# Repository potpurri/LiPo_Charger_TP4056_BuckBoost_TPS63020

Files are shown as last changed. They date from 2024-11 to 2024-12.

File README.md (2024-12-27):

# Lithium Battery Charger and Boost Converter PCB

This PCB is designed to safely charge a lithium-ion cell and provide a selectable 3.3V or 5V output. It's equipped with components that ensure safe charging and protection for the battery and supports flexible output and charging options. 

## Features

- **Charging IC**: TP4056 with adjustable charge currents.
- **Protection Circuitry**: DW01A and F8205A provide overcharge, over-discharge, and overcurrent protection.
- **Buck-Boost Converter**: TPS63020 for stable 3.3V or 5V output, selectable via solder jumper.
- **Compact Design**: Ideal for portable applications, with both top and bottom images of the board for easy identification.
- **Fuse Protection**: Added fuse for enhanced safety of the battery connection.
- **Battery disconnection during charging**: When the USB-C port is connected for charging, the battery is disconnected from the Buck-Boost converter via two p-channel MOSFETs in series, with the gates tied to VBUS of the USB-C input. Power is instead provided to the Buck-Boost converter using a Schottky diode during charging. This circuit can be bypassed using the solder jumper on the bottom side of the PCB.

## Charging Current Settings

The charging current of the TP4056 can be adjusted using solder jumpers on the PCB to meet various requirements. Refer to the table below:

| Solder Jumper Setting | Charging Current |
|---|---|
| J1 | 130 mA |
| J2 | 280 mA |
| J3 | 400 mA |
| J4 | 580 mA |
| J5 | 780 mA |
| J6 | 1000 mA |

## Images

### Schematic
Schematic

### 3D Renderings
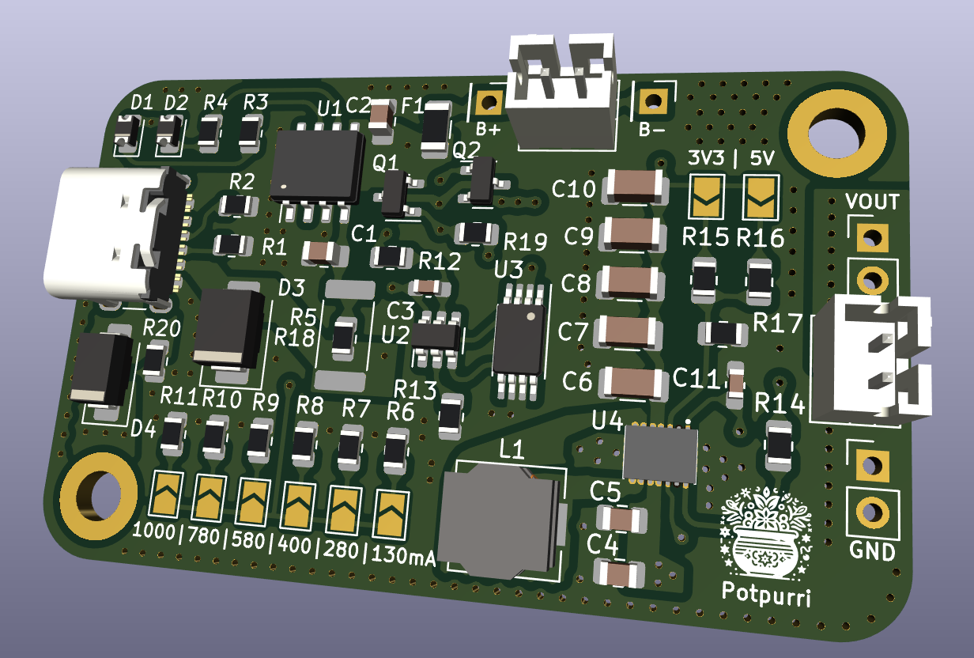
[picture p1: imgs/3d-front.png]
3D Front
- Front View: 
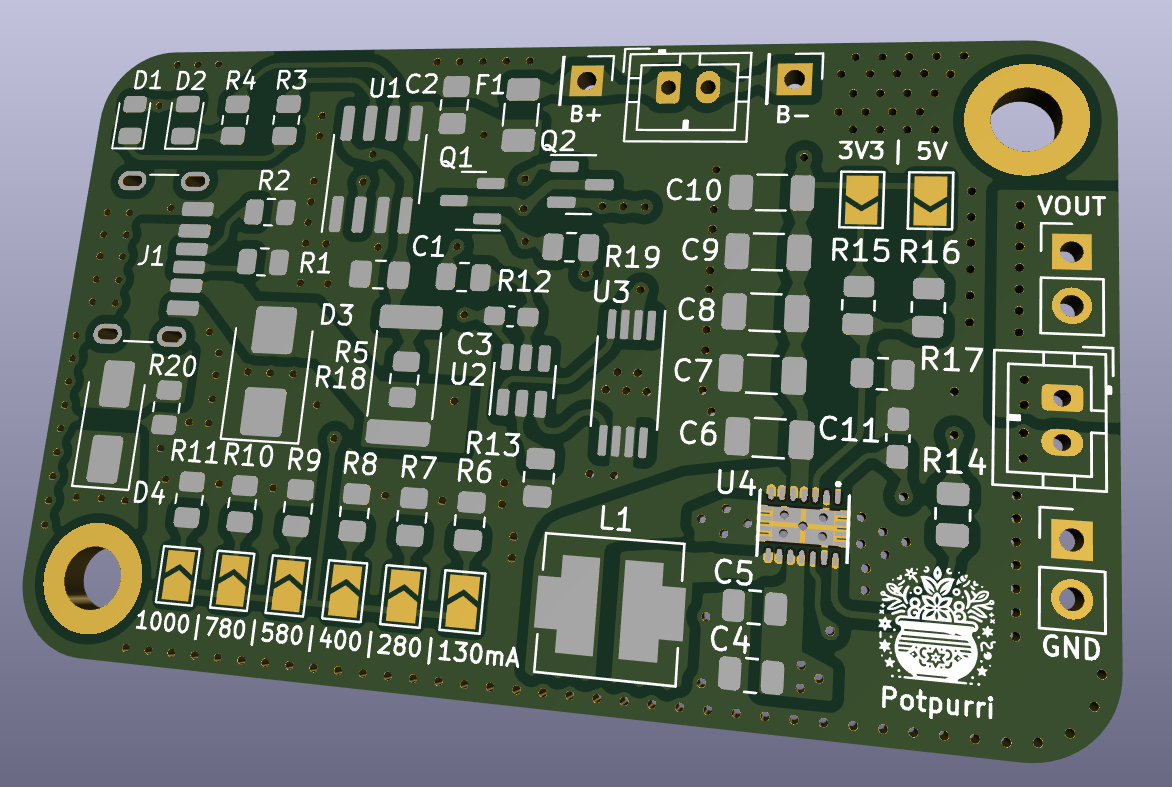
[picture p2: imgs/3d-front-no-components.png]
3D Front
- Front View Without Components: 
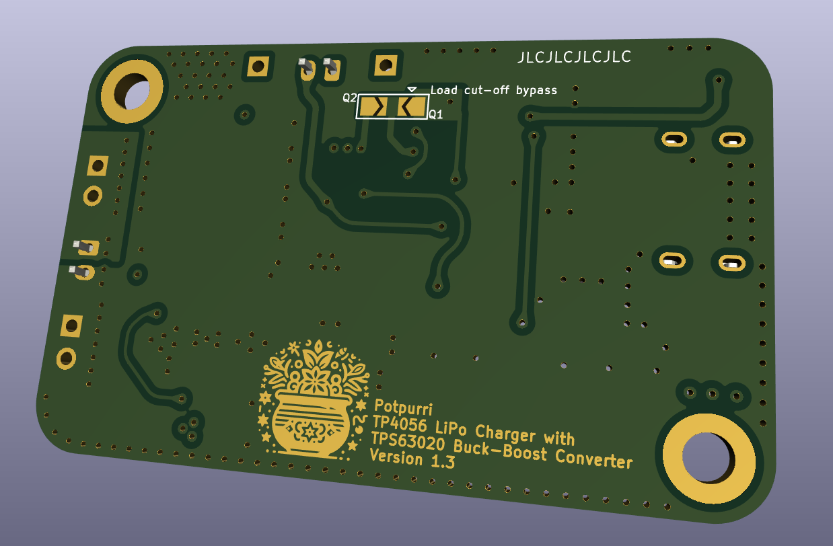
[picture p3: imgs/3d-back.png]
3D Back
- Back View: 

### PCB
**4-Layer Stackup**: Signal Layer, GND Layer, Power Layer, Signal Layer
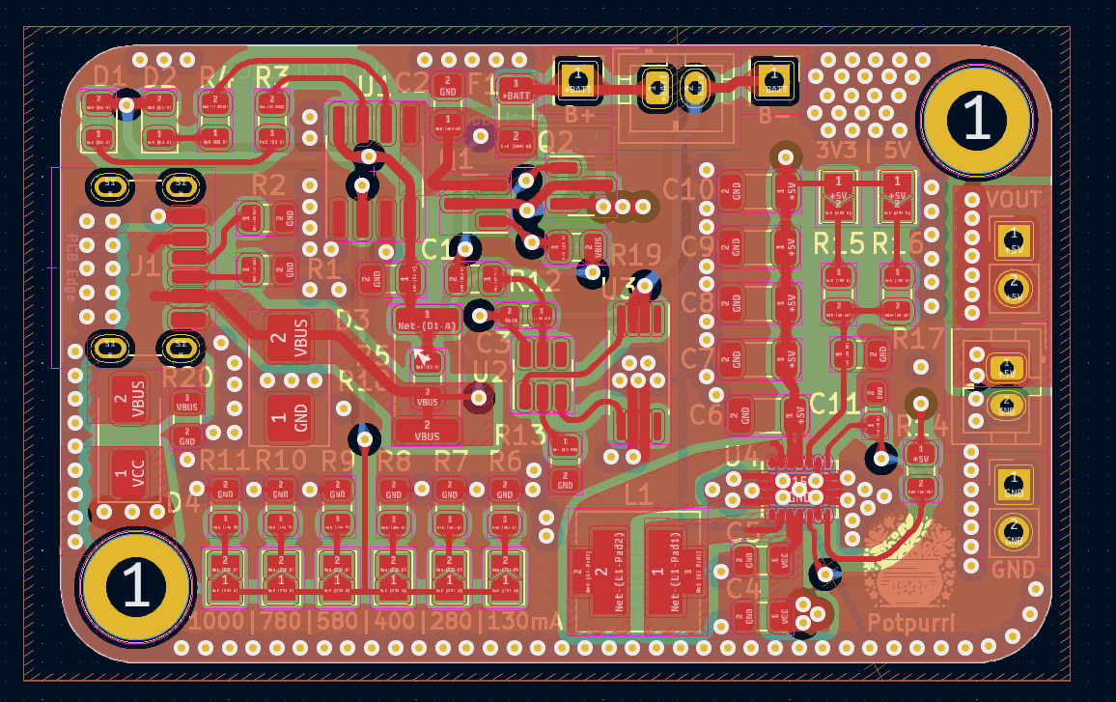
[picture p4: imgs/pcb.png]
PCB - All Layers
- All layers: 
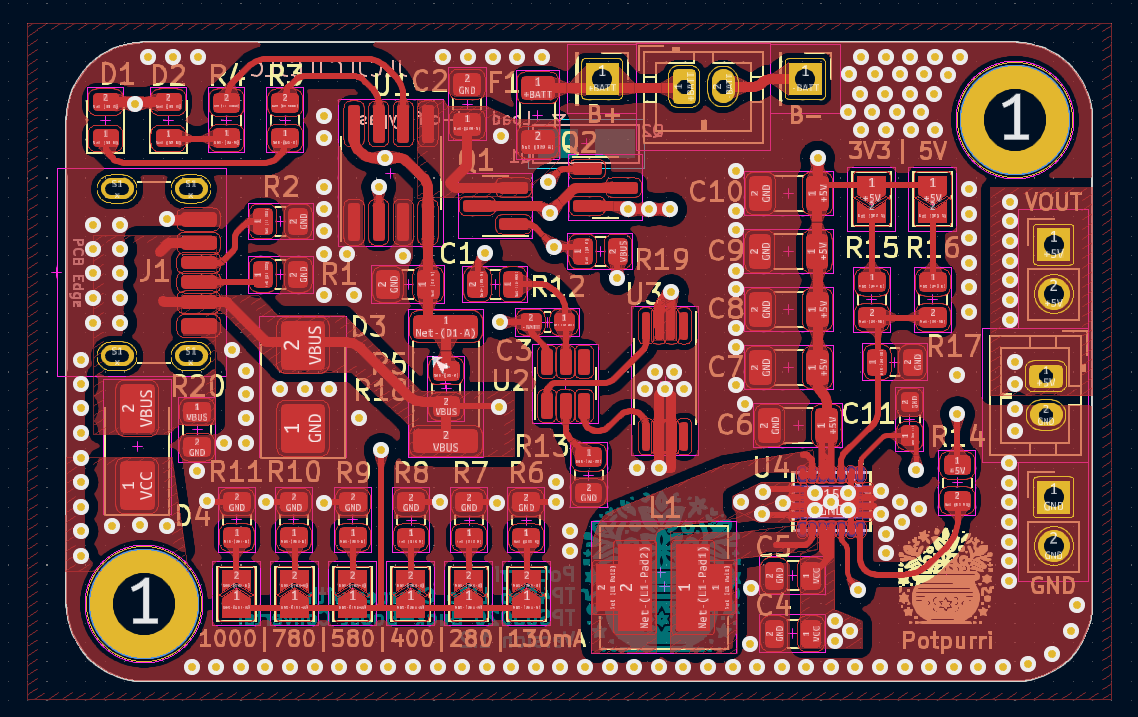
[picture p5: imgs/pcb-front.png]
PCB - Front
- Front traces: 
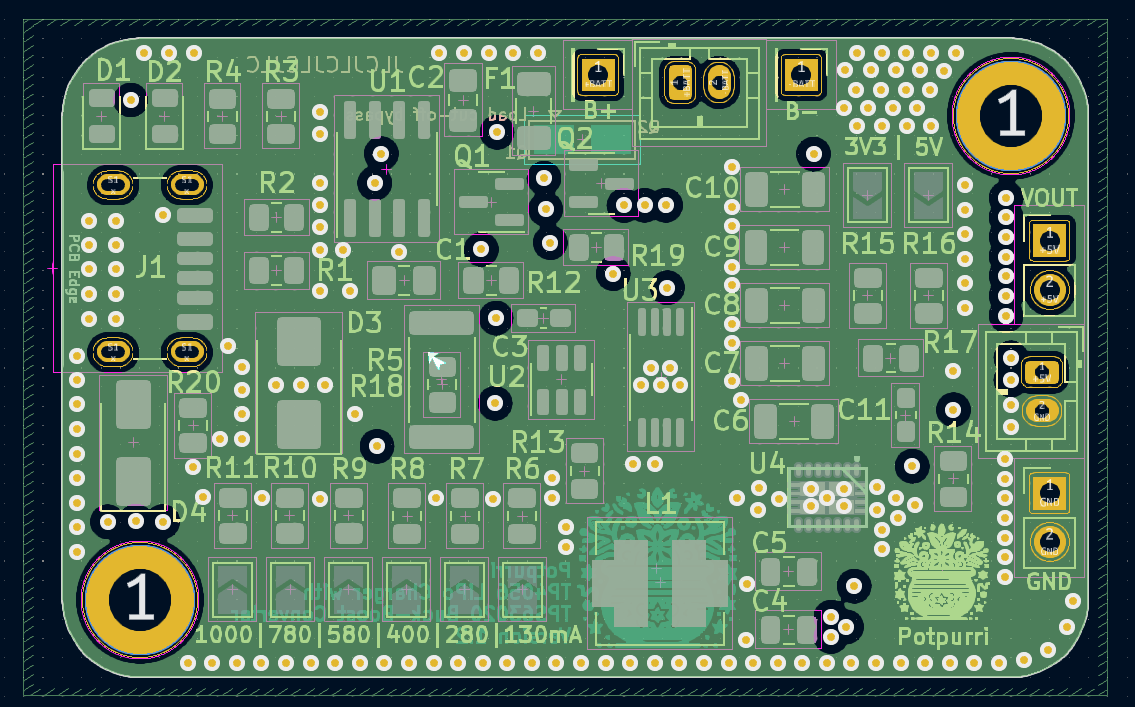
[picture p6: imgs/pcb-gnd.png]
PCB - GND
- GND plane: 
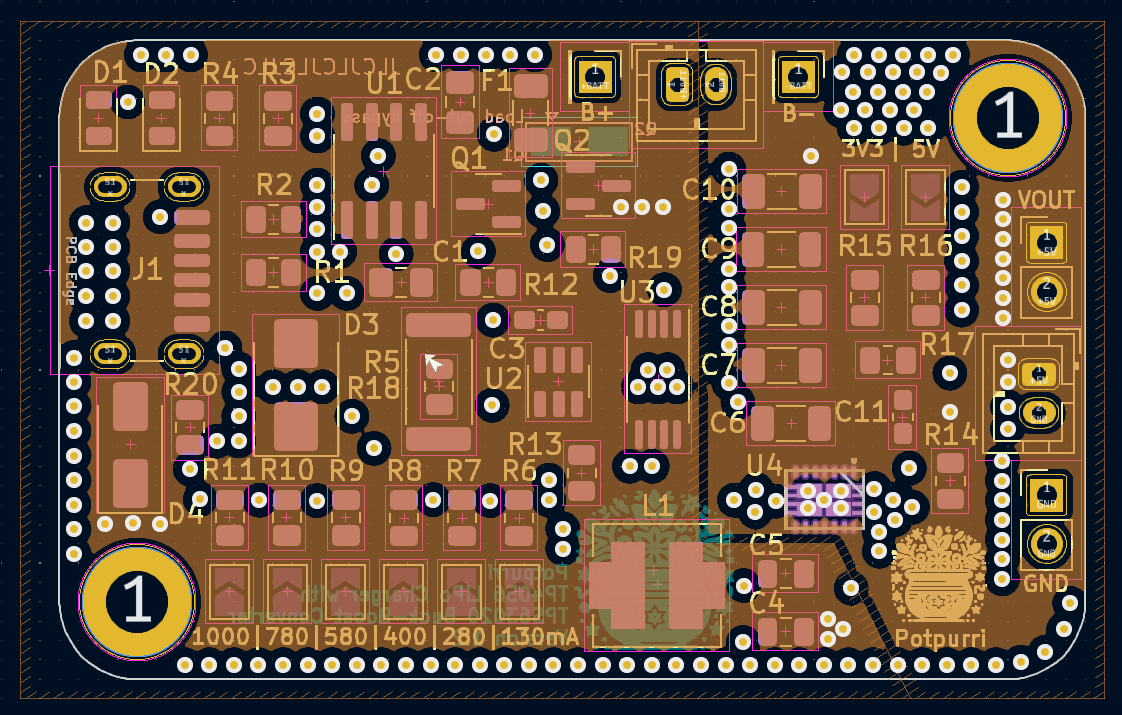
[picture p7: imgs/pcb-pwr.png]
PCB - PWR
- PWR plane: 
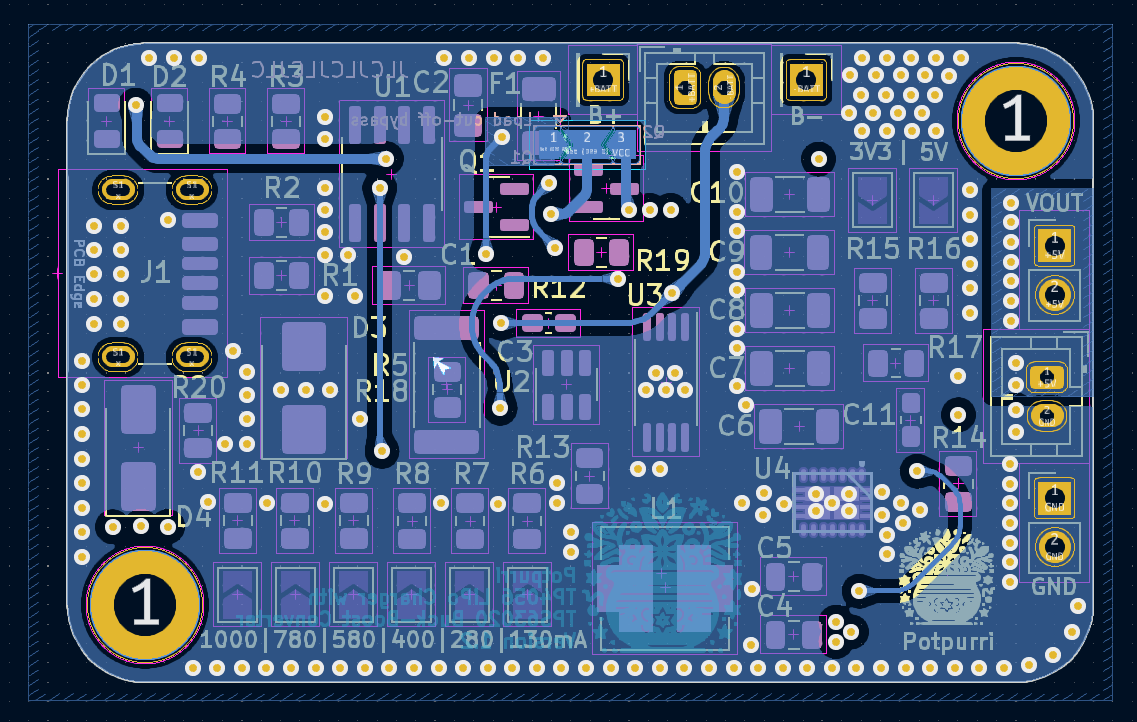
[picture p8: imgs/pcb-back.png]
PCB - Back
- Back traces: 

## Usage

1. **Output Voltage Selection**: Set the desired output voltage (3.3V or 5V) by configuring the solder jumper on the PCB.
2. **Charging Current Selection**: Set the charging current by adjusting the appropriate solder jumper(s) according to the table above.
3. **Connect Battery**: Connect the lithium-ion cell to the battery terminals.
4. **Power Input**: Provide power via the charging input, and the circuit will manage safe charging for the battery and maintain output stability.
5. **Fuse Protection**: Ensure the fuse is correctly in place for additional battery safety.
6. **Battery disconnection during charging**: When the USB-C port is connected, the battery is safely disconnected from the Buck-Boost converter, and power is instead supplied to it from VBUS through a Schottky diode.

---

This board is ideal for applications needing a stable 3.3V or 5V from a lithium-ion cell with enhanced safety and flexibility. With the added features, it provides even more robust protection and usability for various portable electronic projects.

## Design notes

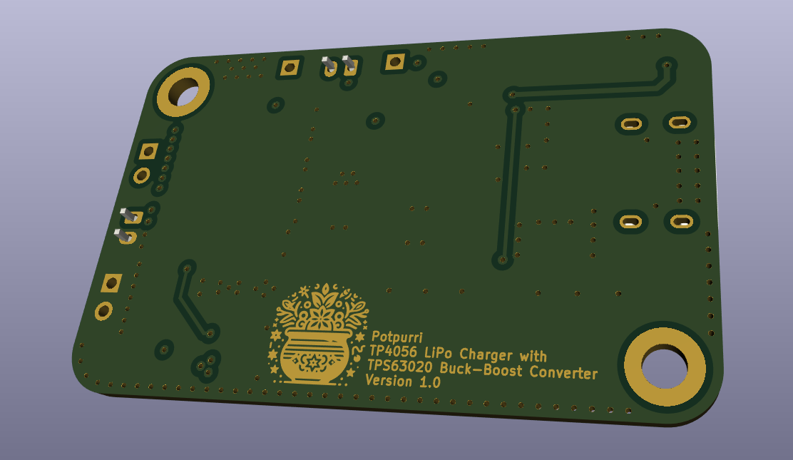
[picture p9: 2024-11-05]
imgs/3d-back-v1.0.png

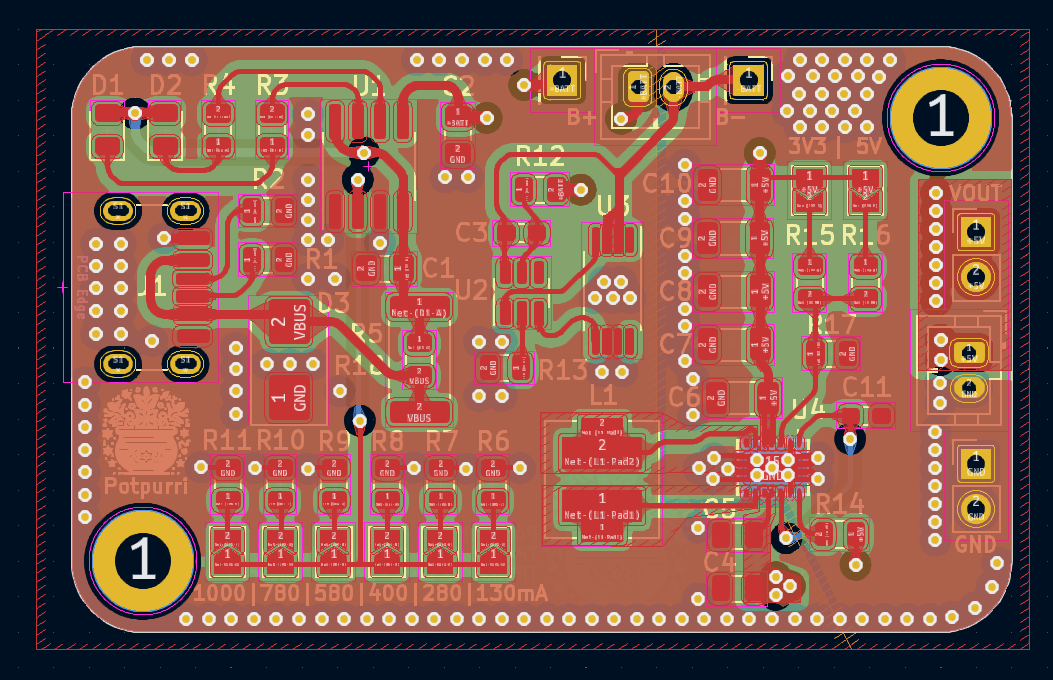
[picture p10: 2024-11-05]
imgs/pcb_v1.1.png

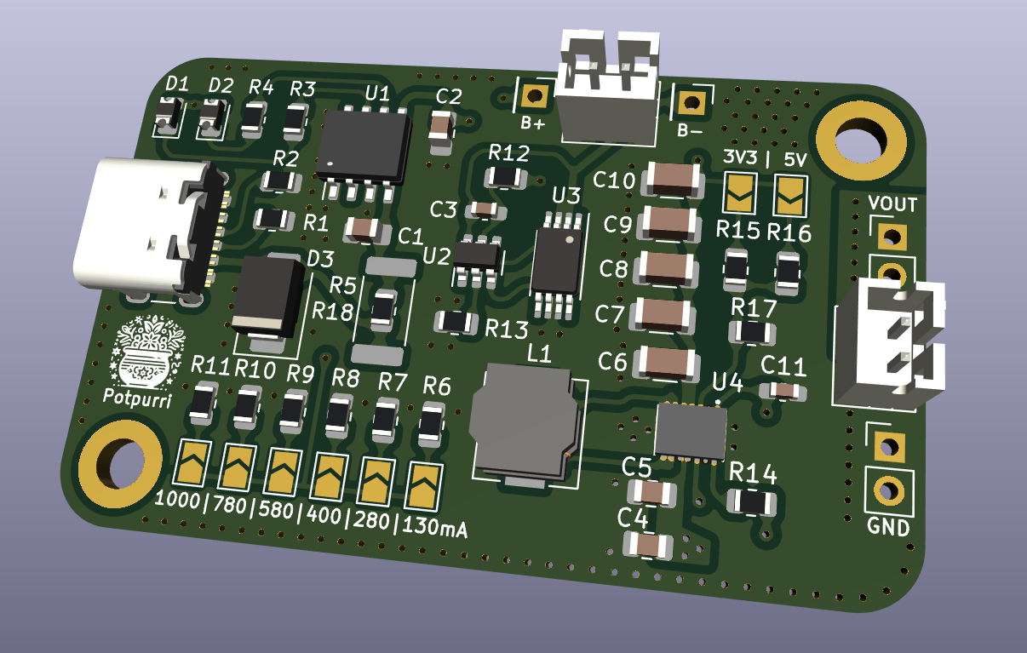
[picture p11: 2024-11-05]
imgs/3d-front-v1.1.png

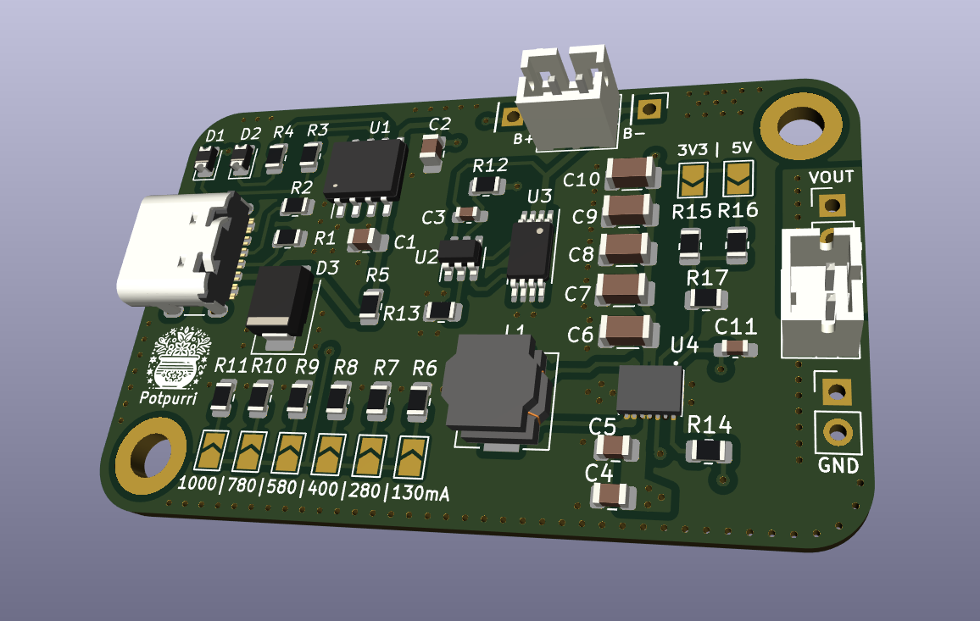
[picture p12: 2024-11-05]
imgs/3d-front-v1.0.png

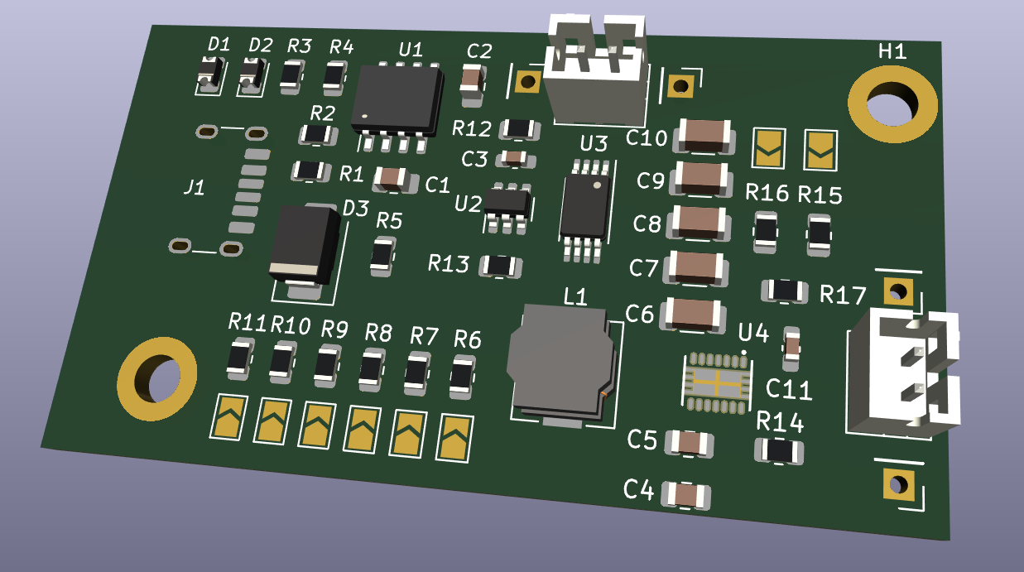
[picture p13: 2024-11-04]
imgs/3d-img.png

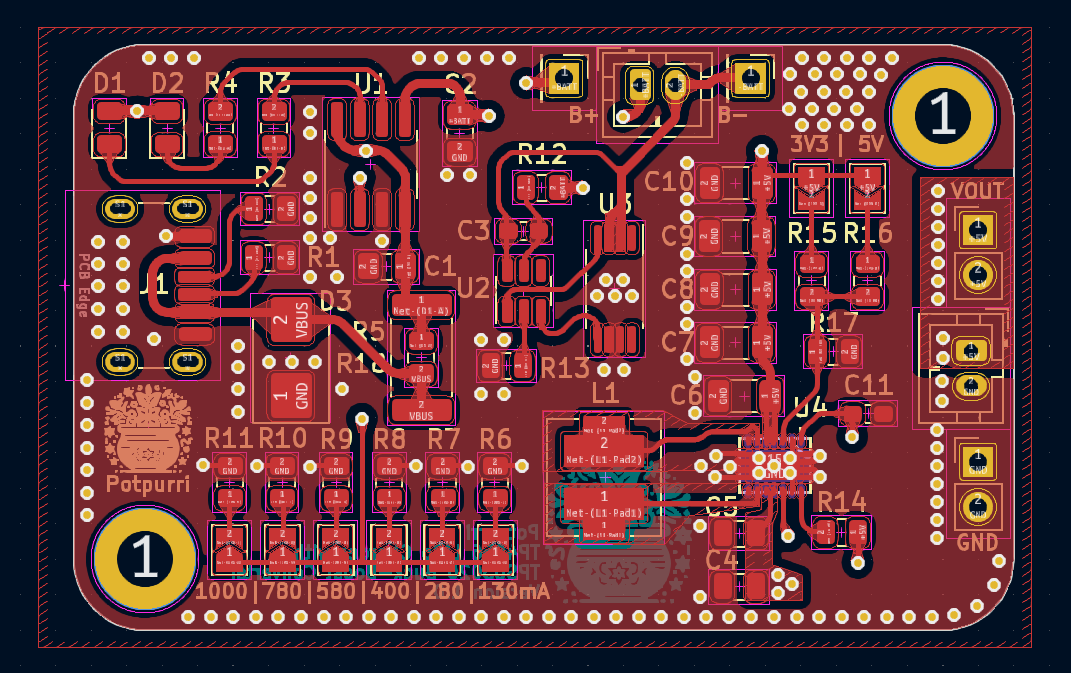
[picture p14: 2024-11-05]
imgs/pcb-front_v1.1.png

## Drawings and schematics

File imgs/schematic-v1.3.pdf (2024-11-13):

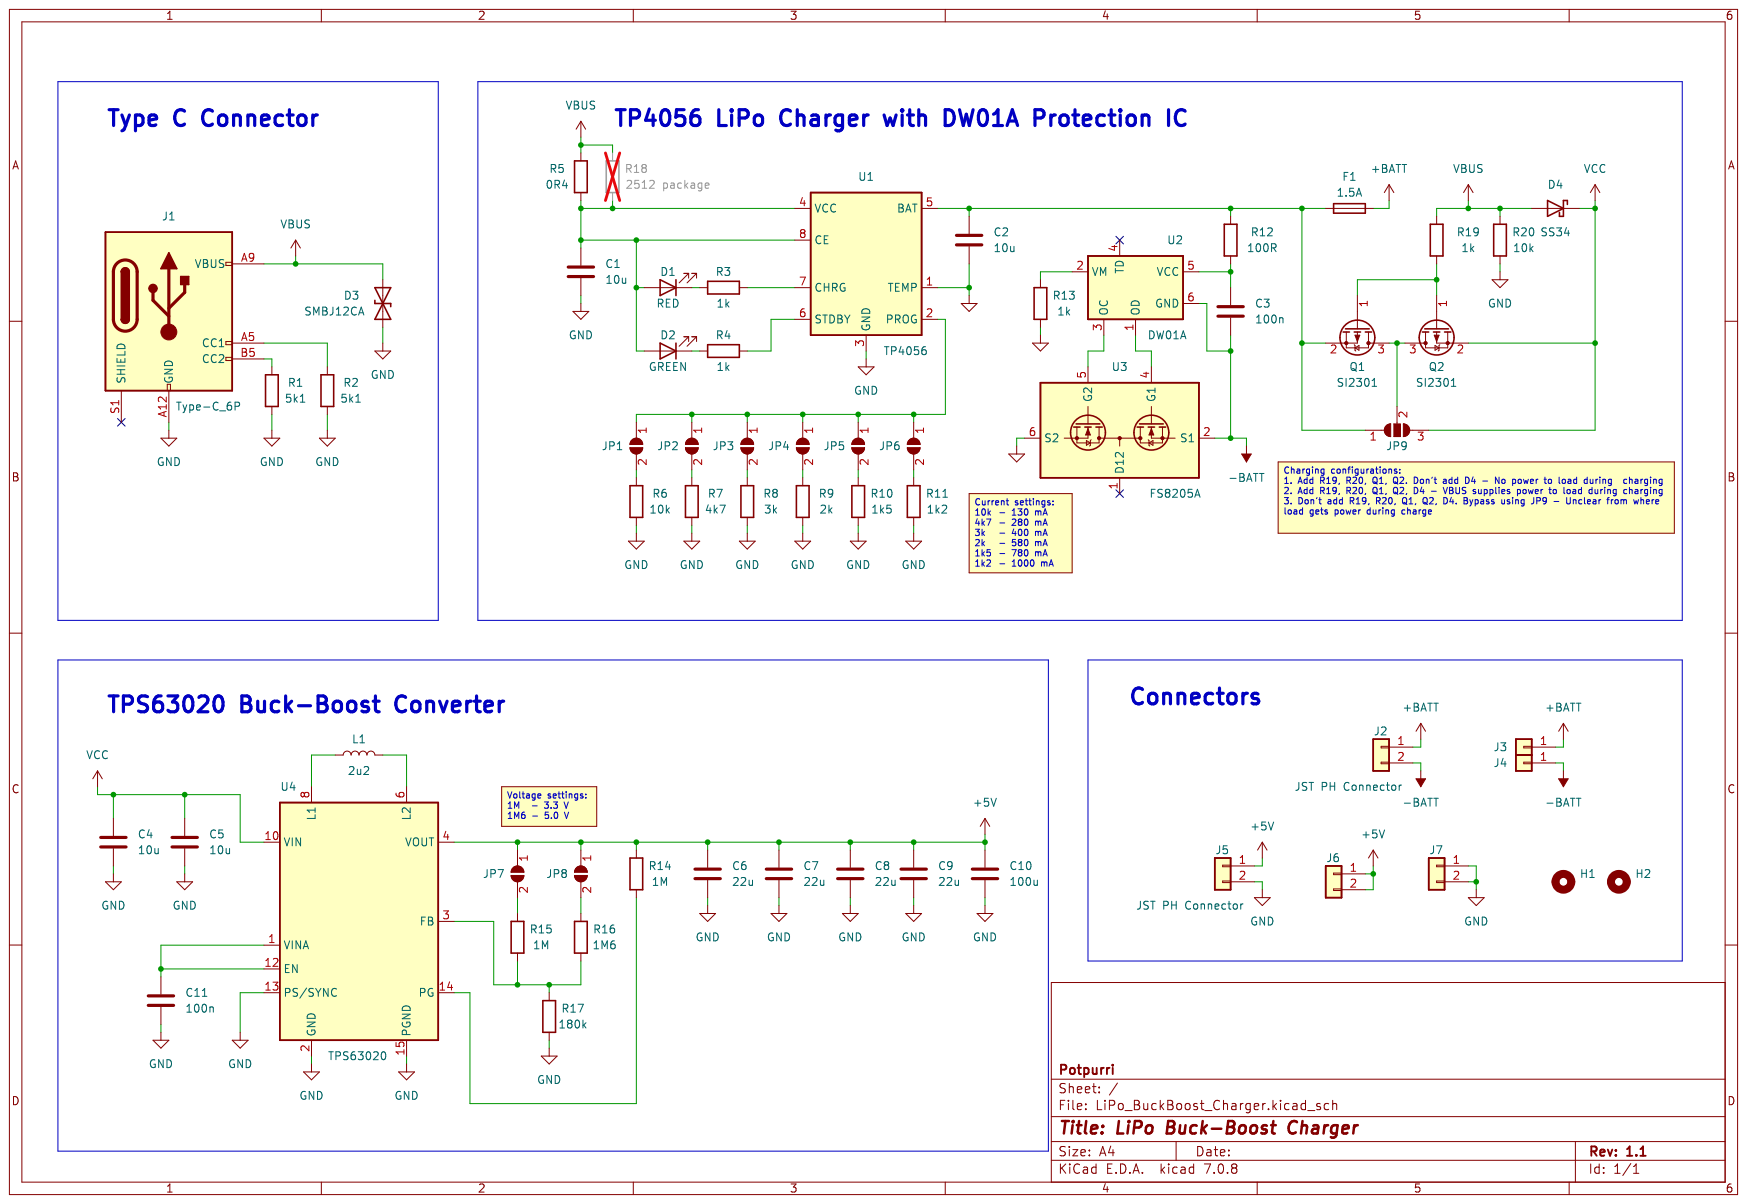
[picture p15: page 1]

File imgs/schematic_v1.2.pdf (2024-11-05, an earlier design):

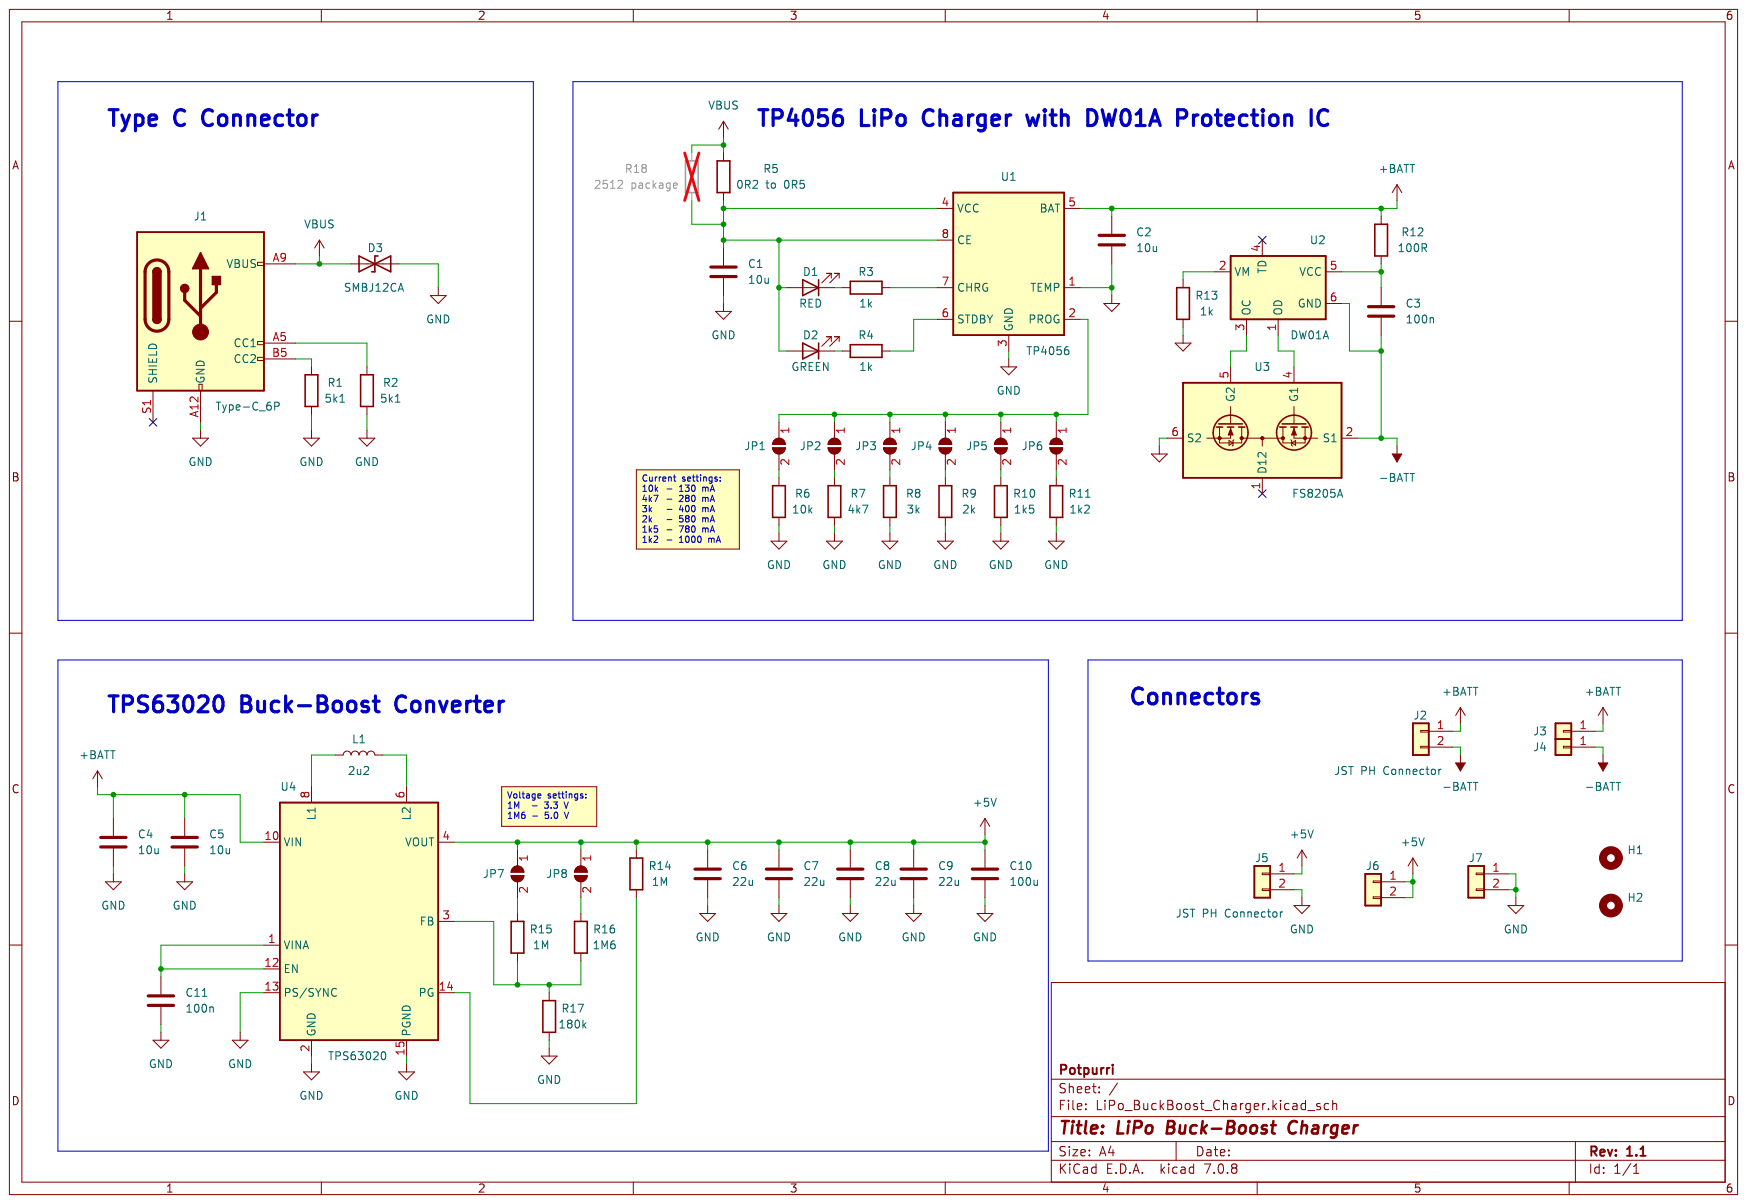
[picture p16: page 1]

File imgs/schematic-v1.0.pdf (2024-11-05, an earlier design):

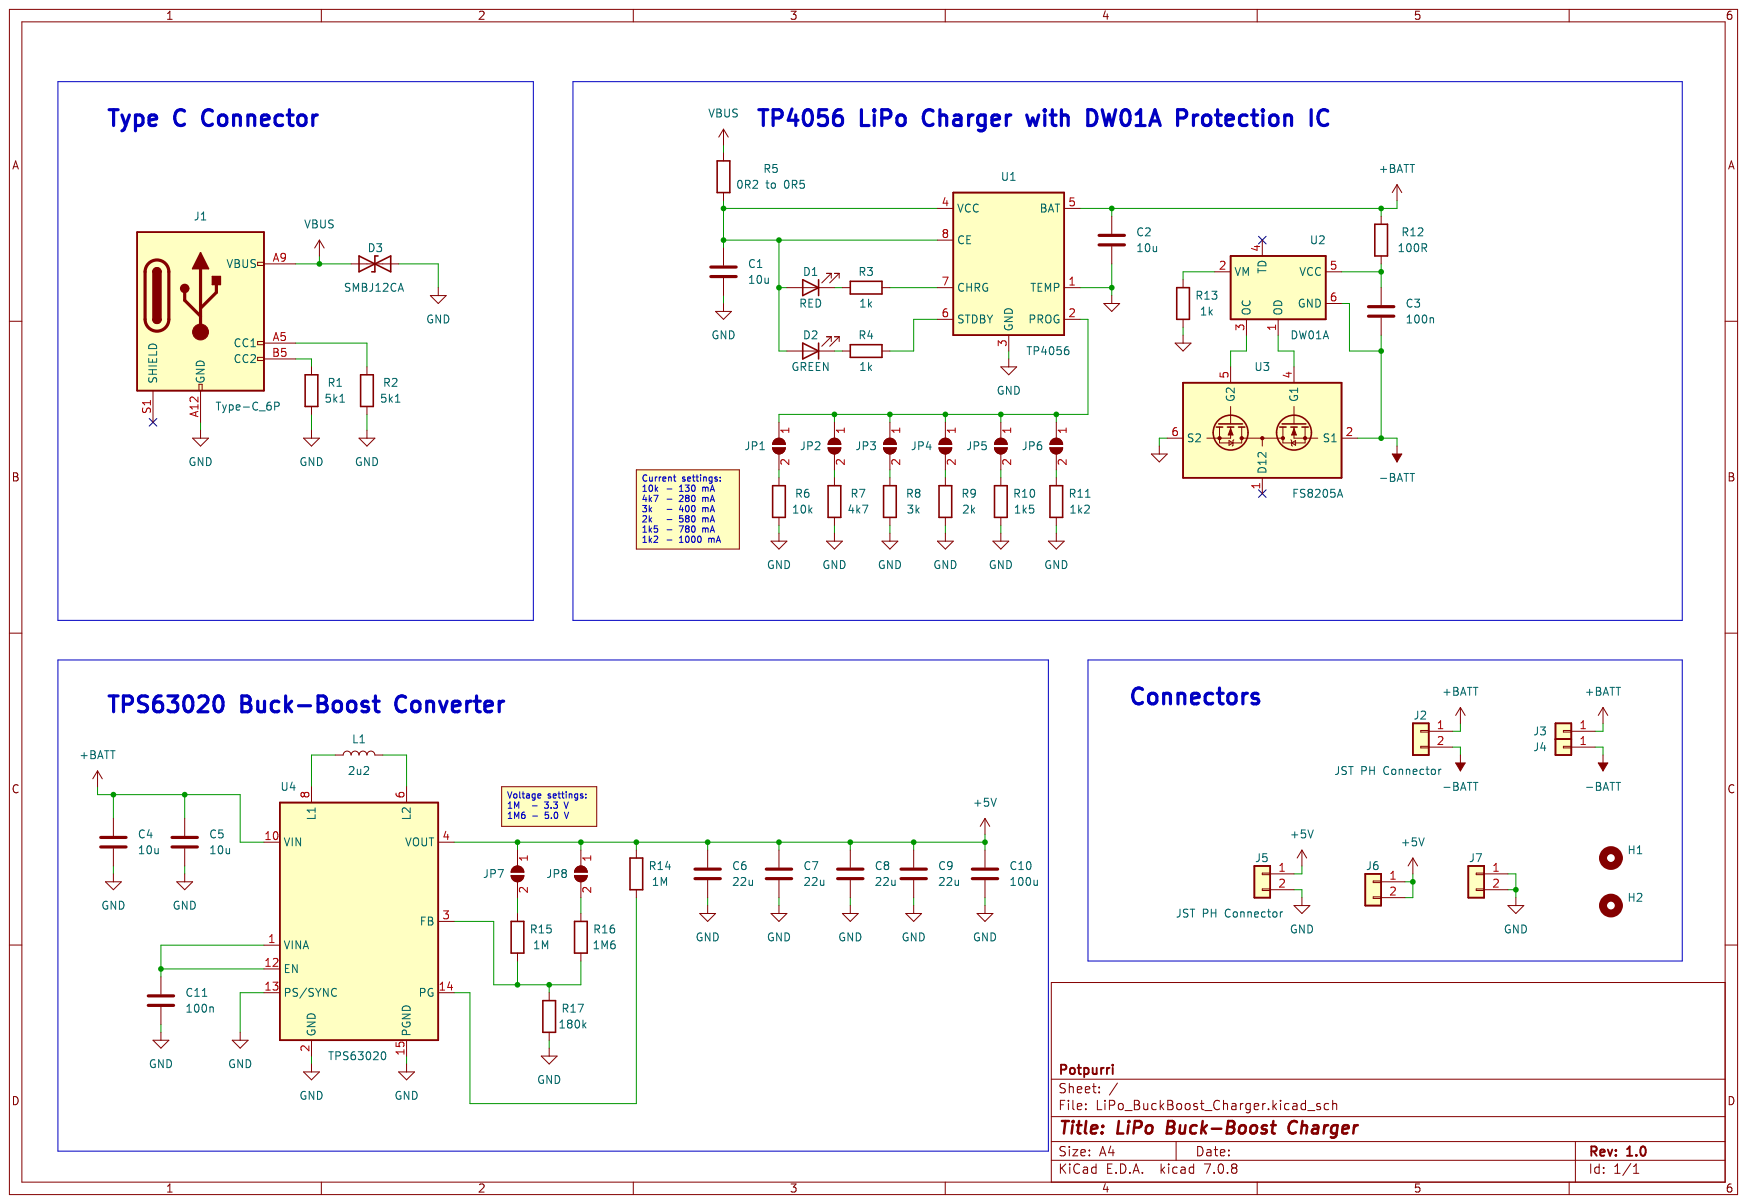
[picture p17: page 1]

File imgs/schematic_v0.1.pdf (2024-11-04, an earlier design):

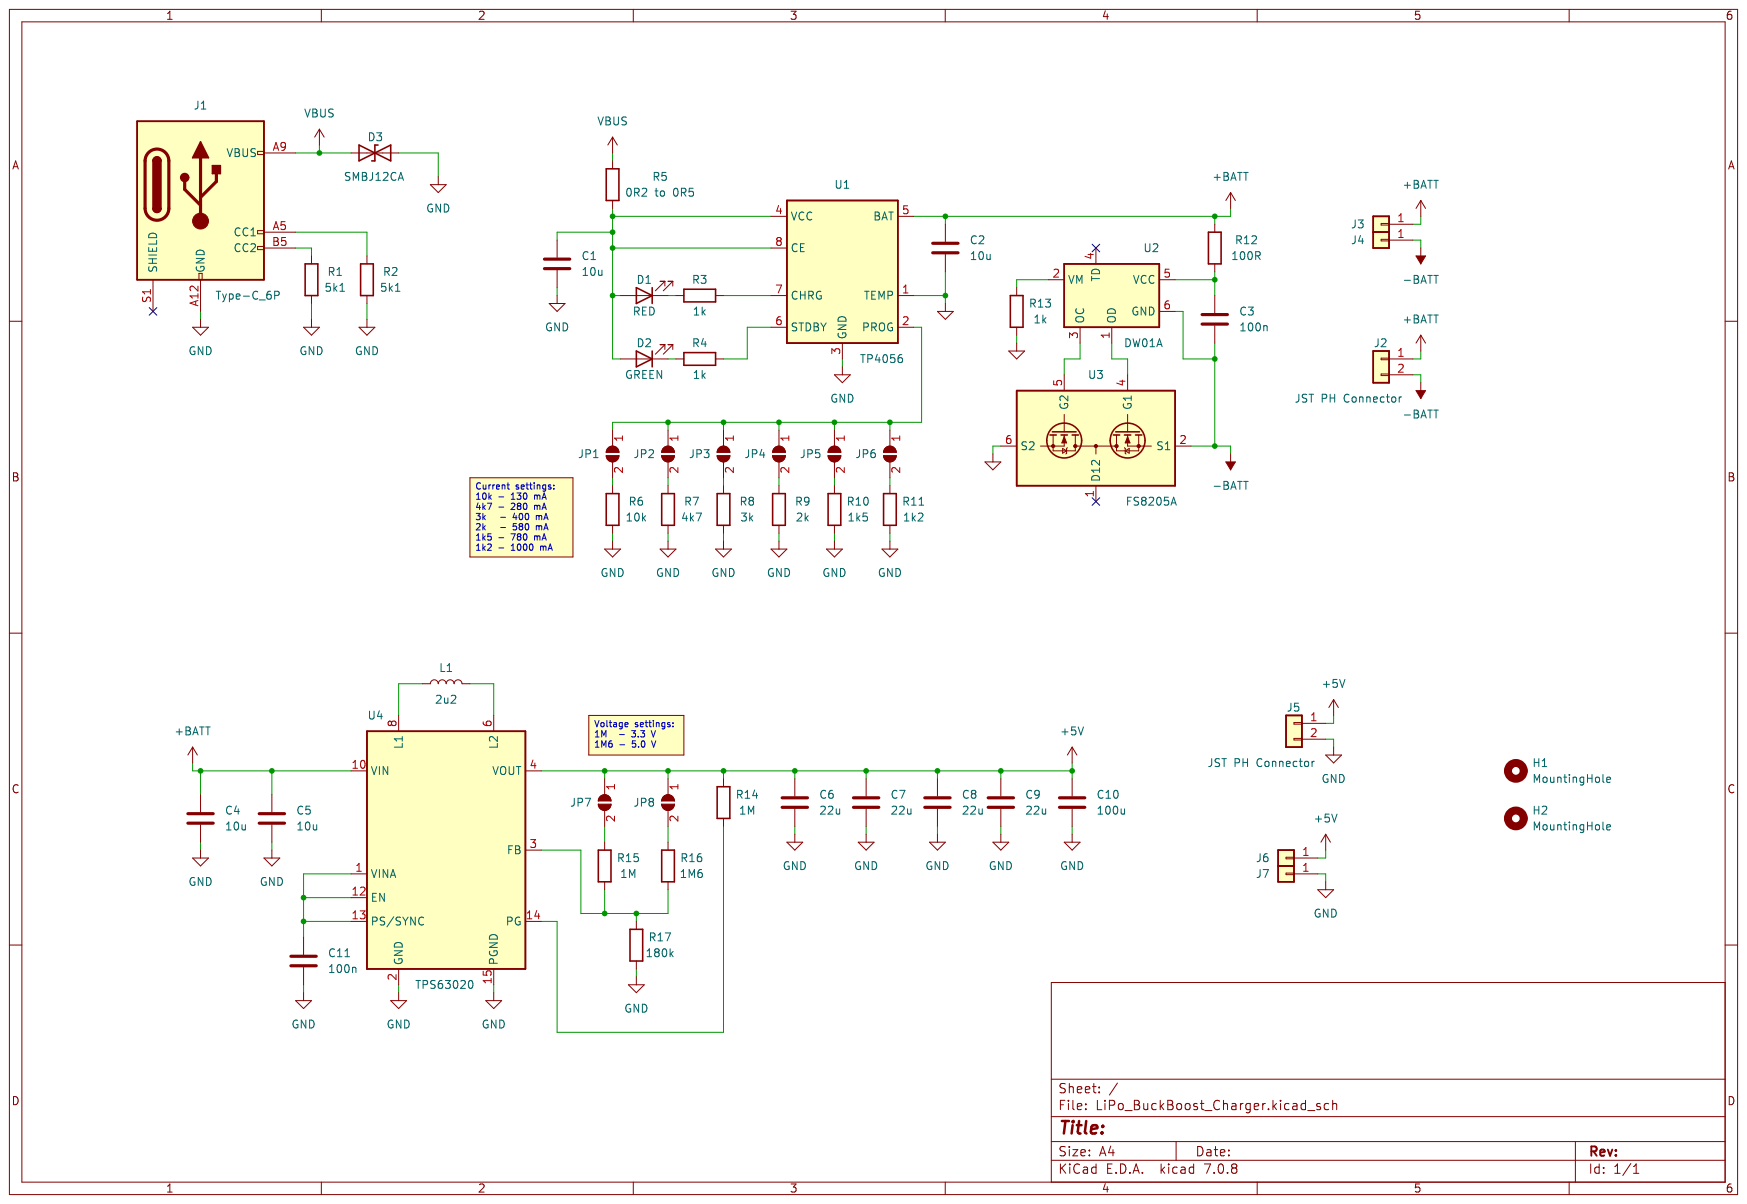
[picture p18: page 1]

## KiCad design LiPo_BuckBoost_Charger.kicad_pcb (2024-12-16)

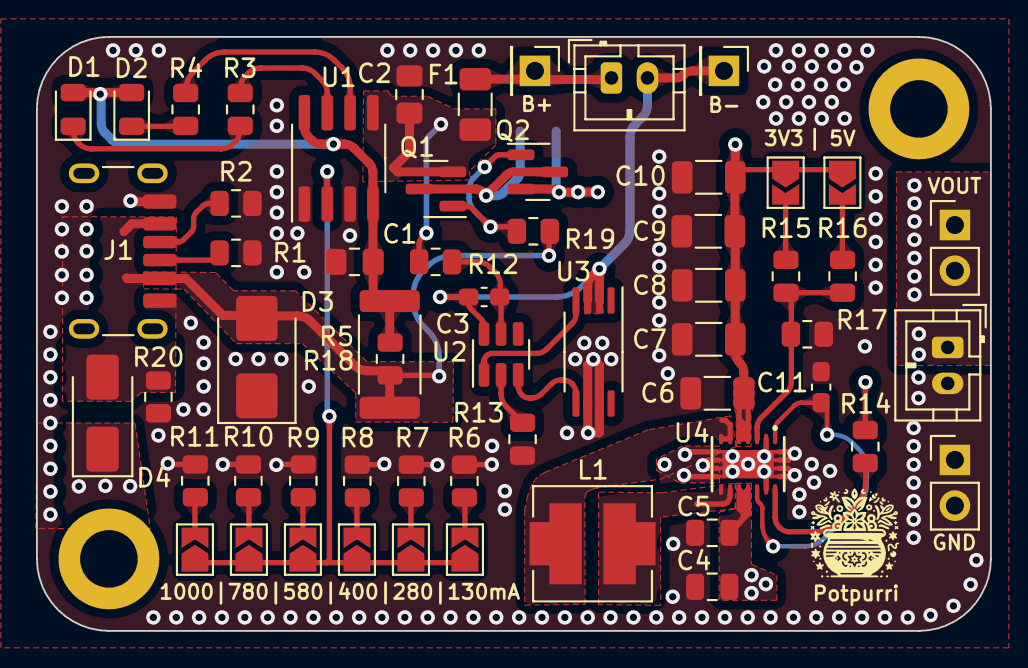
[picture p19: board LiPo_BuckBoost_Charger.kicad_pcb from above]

Board: 4 copper layers, 53.0 x 33.0 mm, 61 parts (1 on the bottom side), 34 nets.

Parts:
C1, C2: 10u; C_0805_2012Metric_Pad1.18x1.45mm_HandSolder
C3, C11: 100n; C_0603_1608Metric_Pad1.08x0.95mm_HandSolder
C4, C5: 10u; C_0805_2012Metric
C6, C7, C8, C9: 22u; C_1206_3216Metric
C10: 100u; C_1206_3216Metric
D1: RED; D_0805_2012Metric
D2: GREEN; D_0805_2012Metric
D3: SMBJ12CA; D_SMB
D4: SS34; D_SMA
F1: 1.5A; Fuse_1206_3216Metric
H1, H2: MountingHole; MountingHole_3.2mm_M3_DIN965_Pad
J1: Type-C_6P; USB-C 6 Pin - Long pads
J2, J5: JST PH Connector; JST_PH_B2B-PH-K_1x02_P2.00mm_Vertical
J3, J4: Conn_01x01; PinHeader_1x01_P2.54mm_Vertical
J6, J7: JST PH Connector; PinHeader_1x02_P2.54mm_Vertical
JP1, JP2, JP3, JP4, JP5, JP6, JP7, JP8: SolderJumper_2_Open; SolderJumper-2_P1.3mm_Open_TrianglePad1.0x1.5mm
JP9: SolderJumper_3_Open; SolderJumper-3_P2.0mm_Open_TrianglePad1.0x1.5mm
L1: 2u2; Combined CD43 + L 6.3x6.3
Q1, Q2: SI2301; SOT-23
R1, R2: 5k1; R_0805_2012Metric
R3, R4, R13: 1k; R_0805_2012Metric
R5: 0R4; R_0805_2012Metric
R6, R20: 10k; R_0805_2012Metric
R7: 4k7; R_0805_2012Metric
R8: 3k; R_0805_2012Metric
R9: 2k; R_0805_2012Metric
R10: 1k5; R_0805_2012Metric
R11: 1k2; R_0805_2012Metric
R12: 100R; R_0805_2012Metric
R14, R15: 1M; R_0805_2012Metric
R16: 1M6; R_0805_2012Metric
R17: 180k; R_0805_2012Metric
R18: 2512 package; R_2512_6332Metric
R19: R; R_0805_2012Metric
U1: TP4056; SOP-8_3.76x4.96mm_P1.27mm
U2: DW01A; SOT-23-6
U3: FS8205A; TSSOP-8_4.4x3mm_P0.65mm
U4: TPS63020; QFN14-3X4MM

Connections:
+5V: C6.1, C7.1, C8.1, C9.1, C10.1, J5.1, J6.1, J6.2, JP7.1 (A), JP8.1 (A), R14.1, U4.4 (VOUT), U4.5 (VOUT)
+BATT: F1.1, J2.1, J3.1
-BATT: C3.2, J2.2, J4.1, U2.6 (GND), U3.2 (S1), U3.3 (S1)
GND: C1.2, C2.2, C4.2, C5.2, C6.2, C7.2, C8.2, C9.2, C10.2, C11.2, D3.1 (A1), J1.A12 (GND), J1.B12 (GND), J5.2, J7.1, J7.2, R1.2, R2.2, R6.2, R7.2, R8.2, R9.2, R10.2, R11.2, R13.2, R17.2, R20.2, U1.1 (TEMP), U1.3 (GND), U3.6 (S2), U3.7 (S2), U4.2 (GND), U4.13 (PS/SYNC), U4.15 (PGND), U4.16 (PGND), U4.17 (PGND), U4.18 (PGND), U4.19 (PGND), U4.20 (PGND), U4.21 (PGND), U4.22 (PGND), U4.23 (PGND)
unnamed: C1.1, D1.2 (A), D2.2 (A), R5.1, R18.1, U1.4 (VCC), U1.8 (CE)
unnamed: D1.1 (K), R3.1
unnamed: D2.1 (K), R4.1
unnamed: J1.A5 (CC1), R2.1
unnamed: J1.B5 (CC2), R1.1
unnamed: JP1.1 (A), JP2.1 (A), JP3.1 (A), JP4.1 (A), JP5.1 (A), JP6.1 (A), U1.2 (PROG)
unnamed: JP1.2 (B), R6.1
unnamed: JP2.2 (B), R7.1
unnamed: JP3.2 (B), R8.1
unnamed: JP4.2 (B), R9.1
unnamed: JP5.2 (B), R10.1
unnamed: JP6.2 (B), R11.1
unnamed: JP7.2 (B), R15.1
unnamed: JP8.2 (B), R16.1
unnamed: C2.1, F1.2, JP9.1 (A), Q1.2 (S), R12.2, U1.5 (BAT)
unnamed: JP9.2 (C), Q1.3 (D), Q2.3 (D)
unnamed: L1.1, U4.8 (L1), U4.9 (L1)
unnamed: L1.2, U4.6 (L2), U4.7 (L2)
unnamed: Q1.1 (G), Q2.1 (G), R19.1
unnamed: R3.2, U1.7 (CHRG)
unnamed: R4.2, U1.6 (STDBY)
unnamed: U2.3 (OC), U3.5 (G2)
unnamed: U2.1 (OD), U3.4 (G1)
unnamed: C3.1, R12.1, U2.5 (VCC)
unnamed: R13.1, U2.2 (VM)
unnamed: C11.1, U4.1 (VINA), U4.12 (EN)
unnamed: R15.2, R16.2, R17.1, U4.3 (FB)
unnamed: R14.2, U4.14 (PG)
VBUS: D3.2 (A2), D4.2 (A), J1.A9 (VBUS), J1.B9 (VBUS), R5.2, R18.2, R19.2, R20.1
VCC: C4.1, C5.1, D4.1 (K), JP9.3 (B), Q2.2 (S), U4.10 (VIN), U4.11 (VIN)

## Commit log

2024-11-04 Schematic and component placing done
    [LiPo_BuckBoost_Charger.kicad_pcb, LiPo_BuckBoost_Charger.kicad_sch]
2024-11-04 added schematic and 3d img
    [LiPo_BuckBoost_Charger.kicad_pcb]
2024-11-04 some traces and gnd vias
    [LiPo_BuckBoost_Charger.kicad_pcb]
2024-11-05 Pcb traces and layout done
    [LiPo_BuckBoost_Charger.kicad_pcb, LiPo_BuckBoost_Charger.kicad_sch]
2024-11-05 schematic update, added imgs
    [LiPo_BuckBoost_Charger.kicad_sch]
2024-11-05 added fillet tracks and tear drops to pcb
    [LiPo_BuckBoost_Charger.kicad_pcb]
2024-11-05 Version 1.1 - added 2512 footprint for input resistor to TP4056
    [LiPo_BuckBoost_Charger.kicad_pcb, LiPo_BuckBoost_Charger.kicad_sch]
2024-11-07 Added jlc serial number silk screen
    [LiPo_BuckBoost_Charger.kicad_pcb]
2024-11-10 v1.2, fixed filled zones for inductor
    [LiPo_BuckBoost_Charger.kicad_pcb]
2024-11-11 added pmos circuit to disconnect battery from load during charging
    [LiPo_BuckBoost_Charger.kicad_sch]
2024-11-13 version 1.3 - added circuit which disconnects battery from load during charging
    [LiPo_BuckBoost_Charger.kicad_pcb, LiPo_BuckBoost_Charger.kicad_sch]
2024-11-13 updated version number on pcb, updated readme
    [LiPo_BuckBoost_Charger.kicad_pcb]
2024-12-16 minor adjustments
    [LiPo_BuckBoost_Charger.kicad_pcb]
2024-12-16 added gerbers
    [LiPo_BuckBoost_Charger-B_Cu.gbr, LiPo_BuckBoost_Charger-B_Mask.gbr, LiPo_BuckBoost_Charger-B_Paste.gbr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]
2024-12-27 fixed faulty schematic link in readme
